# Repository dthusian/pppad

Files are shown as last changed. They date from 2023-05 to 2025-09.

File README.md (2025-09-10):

# pppad/2k

pppad/2k

*Rapid trigger keypad for OSU!*
*Uses a rp2040 microcontroller with hall effect sensors*

* PCB files found in ./keypad
* Requires a magnet attached to the switch stem

## QMK Build instructions

Make example for this keyboard *(after setting up your build environment)*:

    make pppad/2k:default

Flashing example for this keyboard:

    make pppad/2k:default:flash

See the [build environment setup](https://docs.qmk.fm/#/getting_started_build_tools) and the [make instructions](https://docs.qmk.fm/#/getting_started_make_guide) for more information. Brand new to QMK? Start with our [Complete Newbs Guide](https://docs.qmk.fm/#/newbs).

## Bootloader

Enter the bootloader in 2 ways:

* **Bootmagic reset**: Hold down the key at (0,0) in the matrix and plug in the keyboard
* **Keycode in layout**: Press the key mapped to `QK_BOOT` if it is available

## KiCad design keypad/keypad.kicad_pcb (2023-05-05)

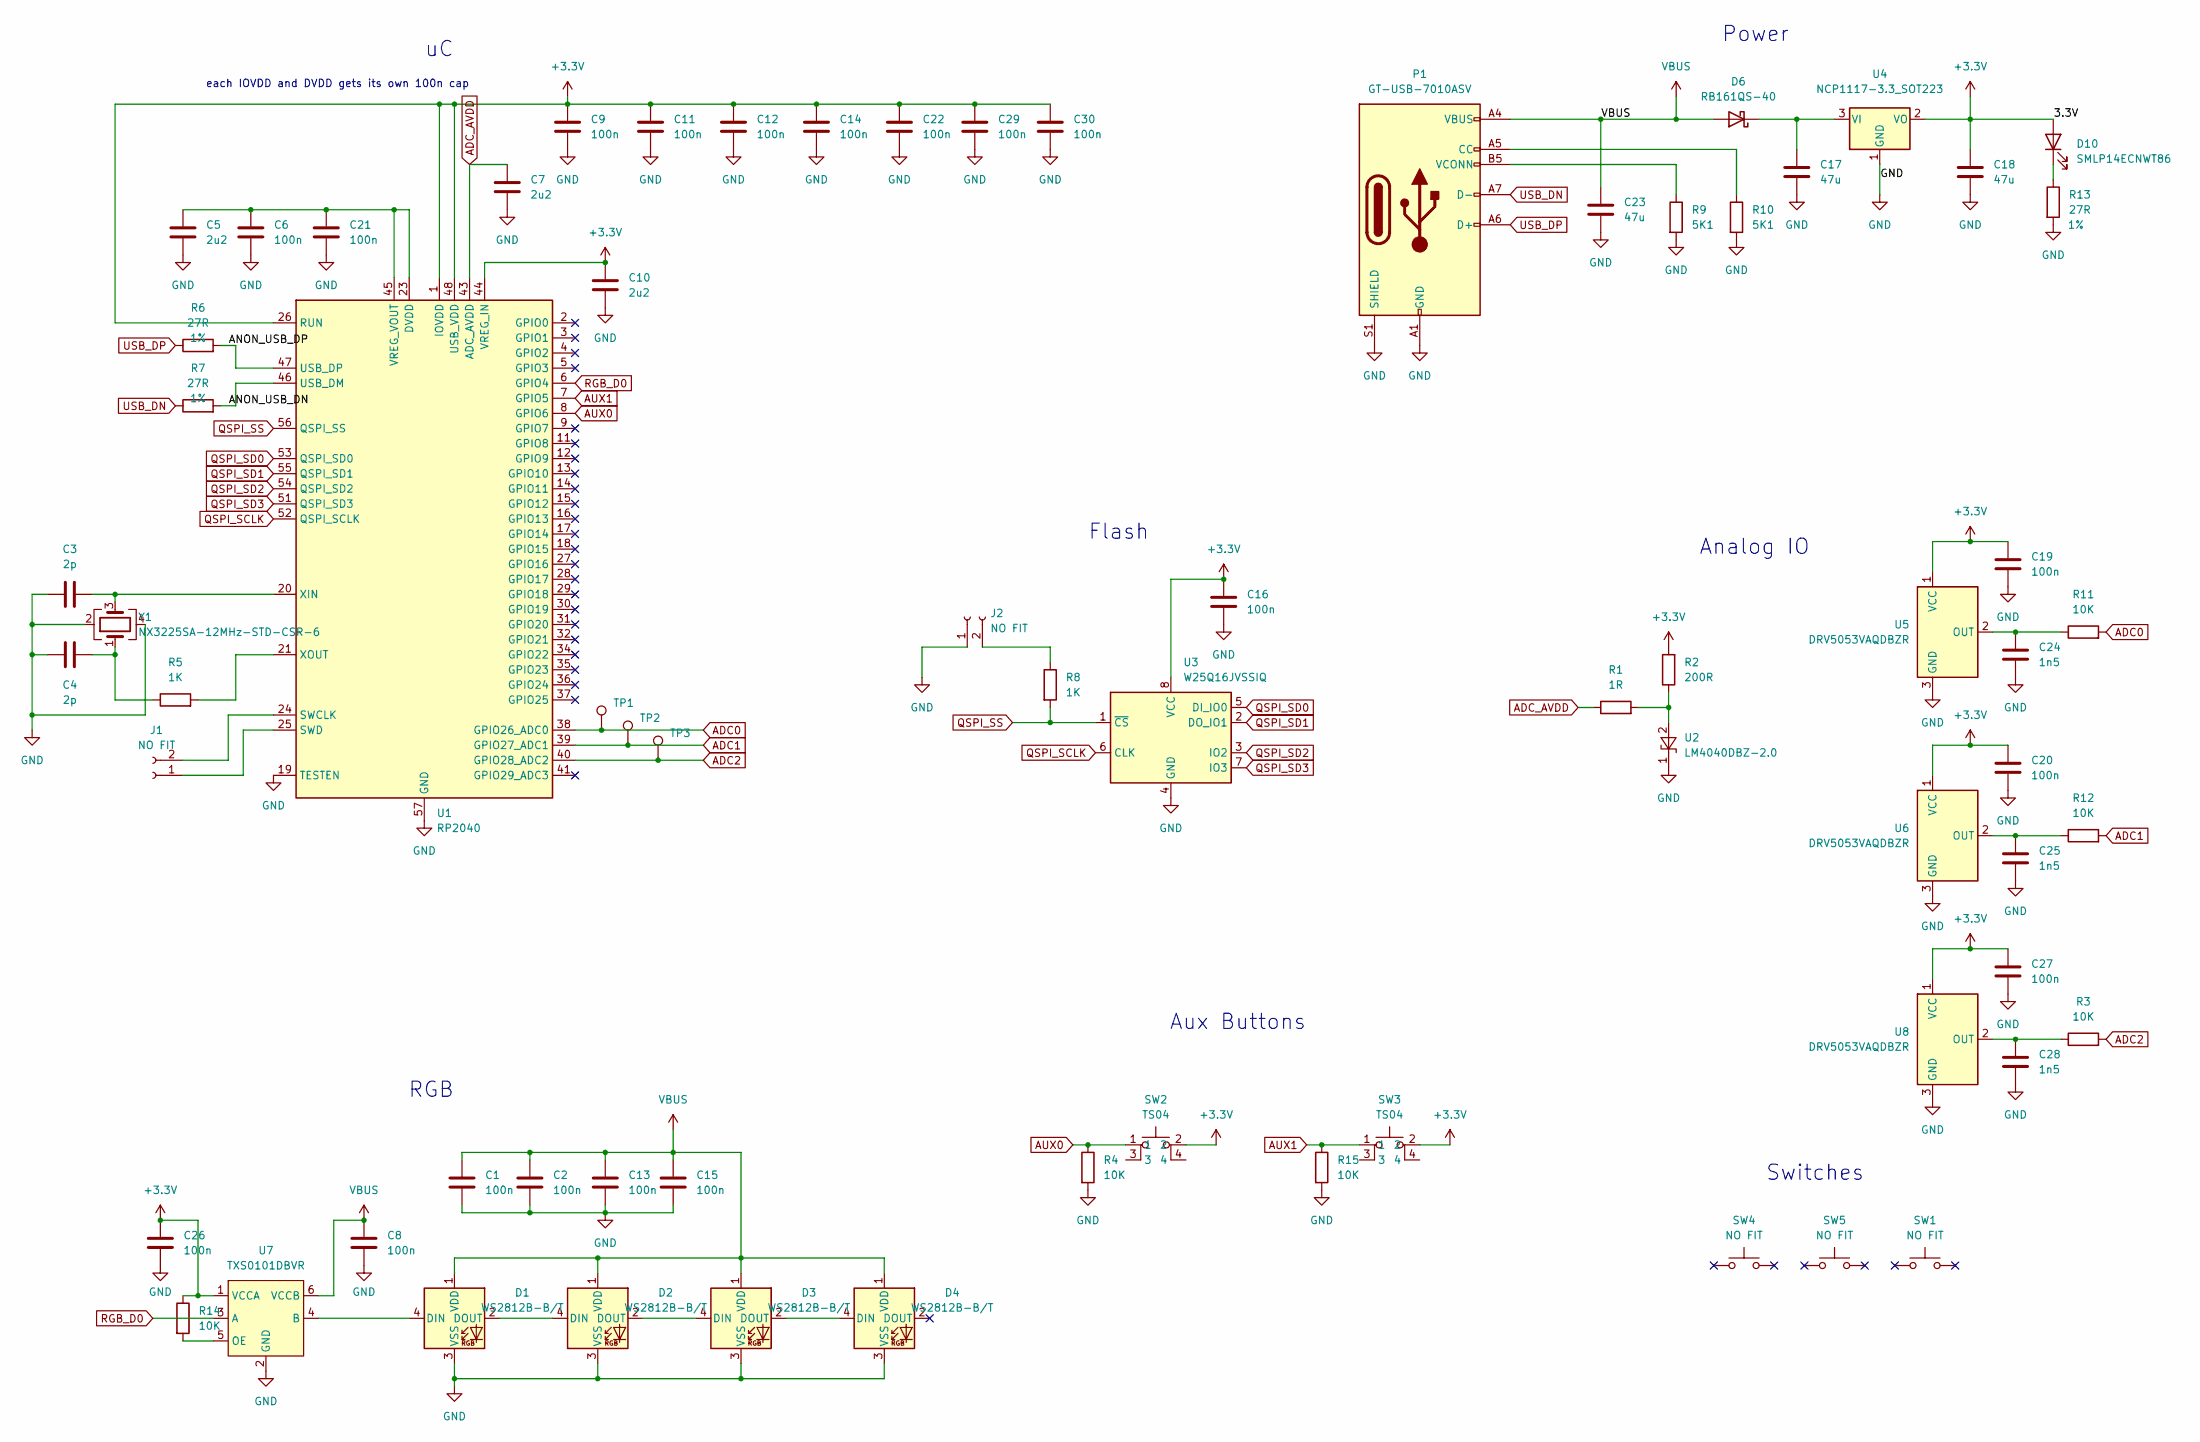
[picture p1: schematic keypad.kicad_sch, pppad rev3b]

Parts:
C1, C2, C6, C8, C9, C11, C12, C13, C14, C15, C16, C19, C20, C21, C22, C26, C27, C29, C30: 100n; C_0805_2012Metric
C3, C4: 2p; C_0805_2012Metric
C5, C7, C10: 2u2; C_0805_2012Metric
C17, C18, C23: 47u; C_0805_2012Metric
C24, C25, C28: 1n5; C_0805_2012Metric
D1, D2, D3, D4: WS2812B-B/T; LED_WS2812B_PLCC4_5.0x5.0mm_P3.2mm
D6: RB161QS-40; D_0402_1005Metric
D10: SMLP14ECNWT86; LED_0603_1608Metric
J1, J2: NO FIT; PinSocket_1x02_P2.00mm_Vertical
P1: GT-USB-7010ASV; USB_C_Receptacle_G-Switch_GT-USB-7010ASV
R1: 1R; R_0805_2012Metric
R2: 200R; R_0805_2012Metric
R3, R4, R11, R12, R14, R15: 10K; R_0805_2012Metric
R5: 1K; R_0805_2012Metric; Tolerance 1%
R6, R7, R13: 27R; R_0805_2012Metric; Tolerance 1%
R8: 1K; R_0805_2012Metric
R9, R10: 5K1; R_0805_2012Metric
SW1, SW4, SW5: NO FIT; SW_Cherry_MX_1.00u_PCB
SW2, SW3: TS04
TP1, TP2, TP3: NO FIT; TestPoint_Pad_1.5x1.5mm
U1: RP2040; QFN-56-1EP_7x7mm_P0.4mm_EP3.2x3.2mm
U2: LM4040DBZ-2.0; SOT-23
U3: W25Q16JVSSIQ; SOIC-8_5.23x5.23mm_P1.27mm
U4: NCP1117-3.3_SOT223; SOT-223-3_TabPin2
U5, U6, U8: DRV5053VAQDBZR; SOT-23
U7: TXS0101DBVR; SOT-23-6
Y1: NX3225SA-12MHz-STD-CSR-6; Crystal_SMD_NX3225SA

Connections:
+3.3V: C9.1, C10.1, C11.1, C12.1, C14.1, C16.1, C18.1, C19.1, C20.1, C22.1, C26.1, C27.1, C29.1, C30.1, D10.2 (A), R2.2, R14.1, SW2.2, SW3.2, U1.1 (IOVDD), U1.10 (IOVDD), U1.22 (IOVDD), U1.26 (RUN), U1.33 (IOVDD), U1.42 (IOVDD), U1.44 (VREG_IN), U1.48 (USB_VDD), U1.49 (IOVDD), U3.8 (VCC), U4.2 (VO), U5.1 (VCC), U6.1 (VCC), U7.1 (VCCA), U8.1 (VCC)
/ANON_USB_DN: R7.2, U1.46 (USB_DM)
/ANON_USB_DP: R6.2, U1.47 (USB_DP)
ADC0: R11.2, TP1.1, U1.38 (GPIO26_ADC0)
ADC1: R12.2, TP2.1, U1.39 (GPIO27_ADC1)
ADC2: R3.2, TP3.1, U1.40 (GPIO28_ADC2)
ADC_AVDD: C7.1, R1.1, U1.43 (ADC_AVDD)
AUX0: R4.1, SW2.1, U1.8 (GPIO6)
AUX1: R15.1, SW3.1, U1.7 (GPIO5)
GND: C1.2, C2.2, C3.1, C4.1, C5.2, C6.2, C7.2, C8.2, C9.2, C10.2, C11.2, C12.2, C13.2, C14.2, C15.2, C16.2, C17.2, C18.2, C19.2, C20.2, C21.2, C22.2, C23.2, C24.2, C25.2, C26.2, C27.2, C28.2, C29.2, C30.2, D1.3 (VSS), D2.3 (VSS), D3.3 (VSS), D4.3 (VSS), J2.1, P1.A1 (GND), P1.A12 (GND), P1.B1 (GND), P1.B12 (GND), P1.S1 (SHIELD), R4.2, R9.2, R10.2, R13.2, R15.2, U1.19 (TESTEN), U1.57 (GND), U2.1 (K), U3.4 (GND), U4.1 (GND), U5.3 (GND), U6.3 (GND), U7.2 (GND), U8.3 (GND), Y1.2, Y1.4
unnamed: C3.2, U1.20 (XIN), Y1.3
unnamed: C4.2, R5.1, Y1.1
unnamed: C17.1, D6.1 (K), U4.3 (VI)
unnamed: C5.1, C6.1, C21.1, U1.23 (DVDD), U1.45 (VREG_VOUT), U1.50 (DVDD)
unnamed: C24.1, R11.1, U5.2 (OUT)
unnamed: C25.1, R12.1, U6.2 (OUT)
unnamed: C28.1, R3.1, U8.2 (OUT)
unnamed: D1.2 (DOUT), D2.4 (DIN)
unnamed: D1.4 (DIN), U7.4 (B)
unnamed: D2.2 (DOUT), D3.4 (DIN)
unnamed: D3.2 (DOUT), D4.4 (DIN)
unnamed: D10.1 (K), R13.1
unnamed: J1.1, U1.25 (SWD)
unnamed: J1.2, U1.24 (SWCLK)
unnamed: J2.2, R8.1
unnamed: P1.A5 (CC), R10.1
unnamed: P1.B5 (VCONN), R9.1
unnamed: R1.2, R2.1, U2.2 (A)
unnamed: R5.2, U1.21 (XOUT)
unnamed: R14.2, U7.5 (OE)
QSPI_SCLK: U1.52 (QSPI_SCLK), U3.6 (CLK)
QSPI_SD0: U1.53 (QSPI_SD0), U3.5 (DI_IO0)
QSPI_SD1: U1.55 (QSPI_SD1), U3.2 (DO_IO1)
QSPI_SD2: U1.54 (QSPI_SD2), U3.3 (IO2)
QSPI_SD3: U1.51 (QSPI_SD3), U3.7 (IO3)
QSPI_SS: R8.2, U1.56 (QSPI_SS), U3.1 (~CS)
RGB_D0: U1.6 (GPIO4), U7.3 (A)
USB_DN: P1.A7 (D-), P1.B7 (D-), R7.1
USB_DP: P1.A6 (D+), P1.B6 (D+), R6.1
VBUS: C1.1, C2.1, C8.1, C13.1, C15.1, C23.1, D1.1 (VDD), D2.1 (VDD), D3.1 (VDD), D4.1 (VDD), D6.2 (A), P1.A4 (VBUS), P1.A9 (VBUS), P1.B4 (VBUS), P1.B9 (VBUS), U7.6 (VCCB)

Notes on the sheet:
Power
Flash
Switches
Analog IO
Aux Buttons
each IOVDD and DVDD gets its own 100n cap
RGB

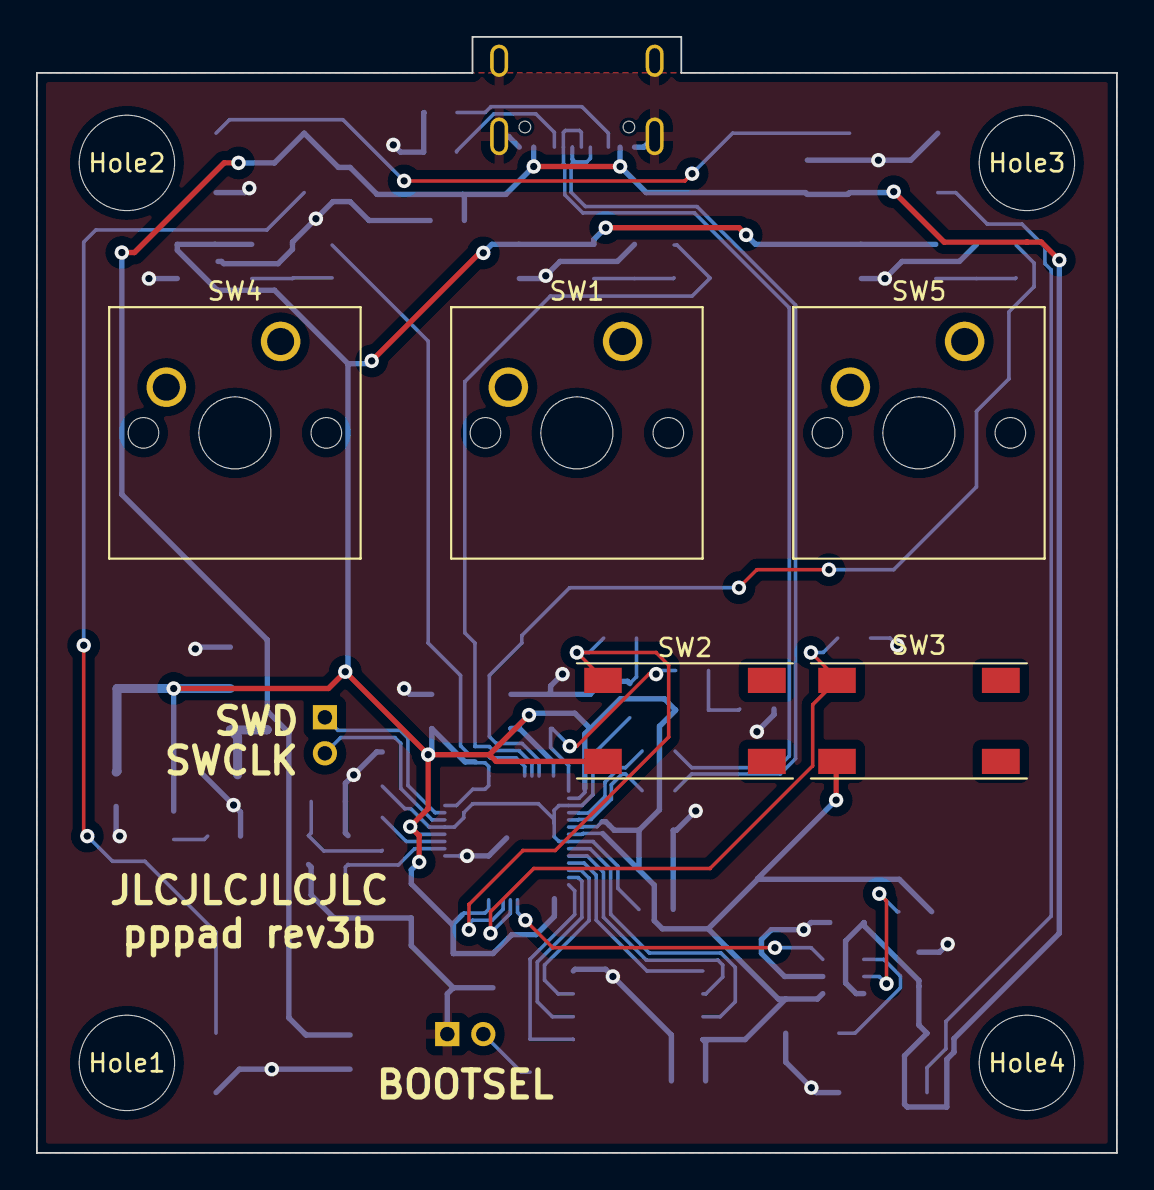
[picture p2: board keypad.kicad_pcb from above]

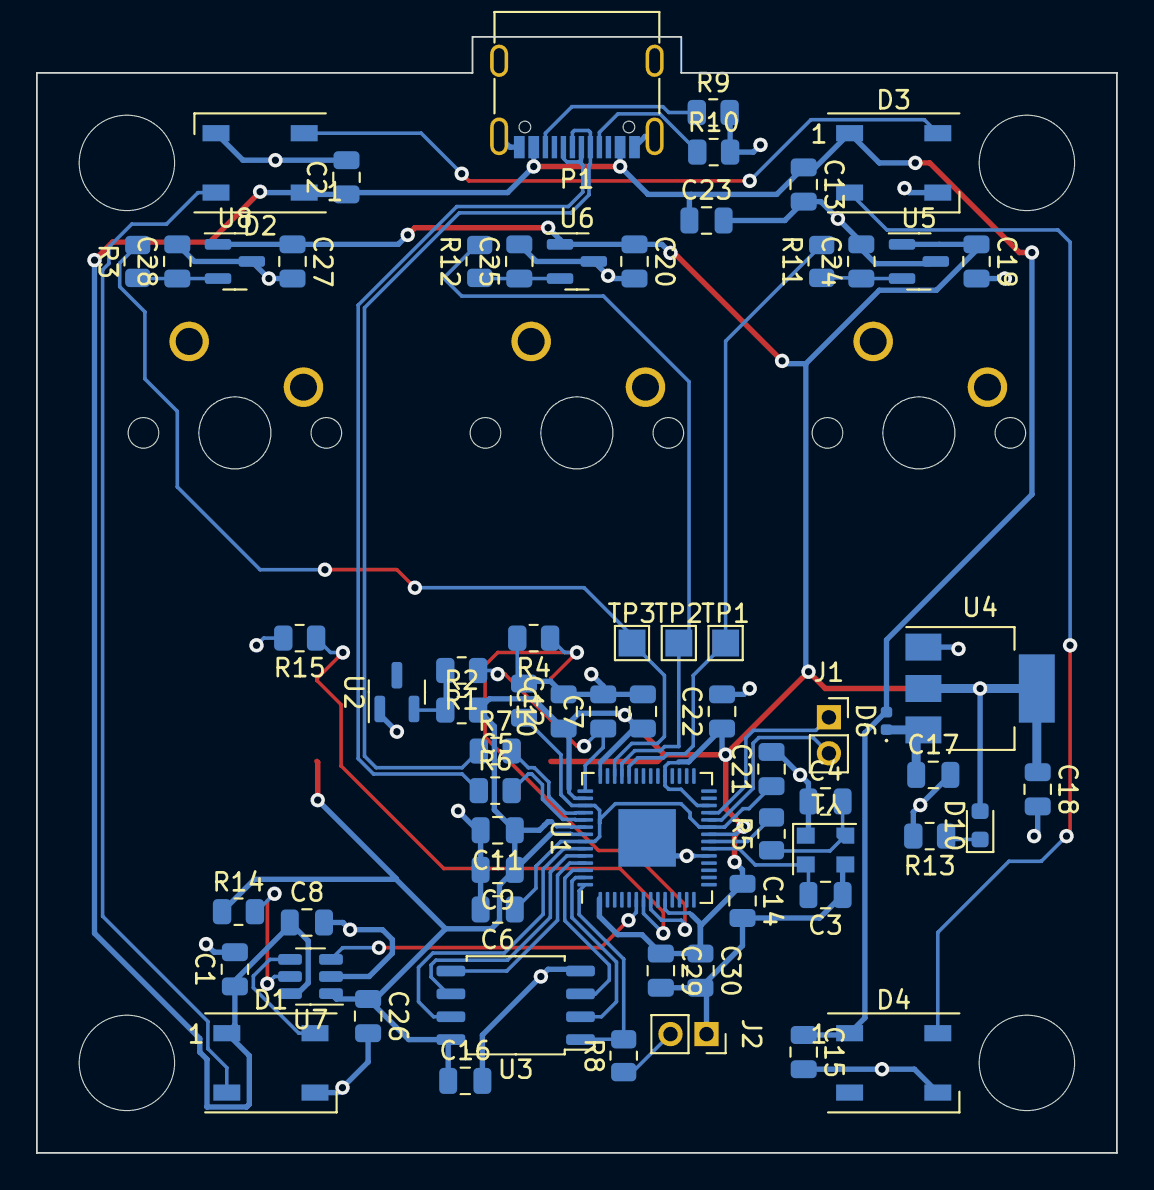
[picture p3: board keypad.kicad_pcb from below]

Board: 2 copper layers, 60.0 x 62.0 mm, 75 parts (66 on the bottom side), 40 nets.

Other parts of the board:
Hole1, Hole2, Hole3, Hole4: MountingHole_5.3mm_M5

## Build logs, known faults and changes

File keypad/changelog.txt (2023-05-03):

changelog between rev2 and rev3a:
- added more decoupling caps on ws2812s
- increased capacitance on some pwr supply filtering caps
- added rc filter on the output of the he sensors
- increased size of swd header to 2mm holes and changed bootsel from a pad to a 2mm hole header
- rerouted adc traces to avoid usb
- added a power on led and an activity led attached to a gpio on the rp2040
- changed adc_aref from a voltage divider to using a shunt resistor
- reduced board edge near the usb connector

changelog between rev3a and rev3b:
- moved everything to backside
- added another key
- removed aux buttons
- removed top rgbs

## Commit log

2023-04-08 velcome to os
    [keypad.kicad_pcb, keypad.kicad_sch]
2023-04-10 Finish RGB and start power
    [keypad.kicad_pcb, keypad.kicad_sch]
2023-04-11 finish placing everything
    [keypad.kicad_pcb, keypad.kicad_sch]
2023-04-11 fix all the disconnected GND problems
    [keypad.kicad_pcb]
2023-04-11 Rewire RGB to add space for screwholes
    [keypad.kicad_pcb, keypad.kicad_sch]
2023-04-11 Re-spec USB-C and power diode
    [keypad.kicad_pcb, keypad.kicad_sch]
2023-04-15 Minor updates, prep for fab
    [keypad.kicad_pcb, keypad.kicad_sch]
2023-04-17 fix mistakes because i am big dum
    [keypad.kicad_pcb, keypad.kicad_sch]
2023-04-17 realign everything
    [keypad.kicad_pcb]
2023-04-17 move switches slighltly
    [keypad.kicad_pcb]
2023-04-17 Size increase to accomodate for mechanical
    [keypad.kicad_pcb]
2023-04-19 fix up stuff for fab
    [keypad.kicad_pcb]
2023-05-02 Make alterations for rev3
    [keypad.kicad_pcb, keypad.kicad_sch]
2023-05-03 ditch rev3a for rev3b
    [keypad.kicad_pcb, keypad.kicad_sch]
2023-05-04 initial placements for rev3b
    [keypad.kicad_pcb, keypad.kicad_sch]
2023-05-05 finish rev3b
    [keypad.kicad_pcb, keypad.kicad_sch]
2023-05-05 add helpful silkscreening
    [keypad.kicad_pcb]
